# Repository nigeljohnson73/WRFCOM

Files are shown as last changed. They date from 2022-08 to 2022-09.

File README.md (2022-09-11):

# Water Rocket Flight Computer

For more background and discussion, check out [the wiki](https://github.com/nigeljohnson73/WRFCOM/wiki).

This is a small project that uses off the shelf modules as much as possible to build a data logger for attaching to a 
water bottle rocket... or any kind of vehicle. The idea is that is uses various sensors to define your position in 
3 dimensions with some additional parameters from Gyros, Accelerometers and magnetometers. All of this data being 
logged to an SD card as fast as possible and running from a small battery. The interface should be a web page from the 
on-board WiFi Access Point.

See the '[BLE Remote Controller](https://github.com/nigeljohnson73/WRFCOM-Remote)' for more on a BLE interface.

I make no apologies for the really bad coding here, and there are much better ways to do a lot of this. If you can 
help, please let me know.

Things to install
-----------------
I will assume you are comfortable with the Arduino IDE.

You should install the latest ESP boards into your board manager if you haven't already (depending on which you 
want to use). You can only install the ESP32 bitis if you are using the out-of-the-box stuff in this project.
Add these to your "Additional Boards Manager URLs" section in preferences.

```
https://arduino.esp8266.com/stable/package_esp8266com_index.json
https://raw.githubusercontent.com/espressif/arduino-esp32/gh-pages/package_esp32_dev_index.json
```

With that installed the board you want is the `Adafruit Feather ESP32-S3 No PSRAM` for the out-of-the-box project.

<!--
You will need to install the file system plugins for 
[ESP32](https://microcontrollerslab.com/install-esp32-filesystem-uploader-in-arduino-ide-spiffs/) and/or 
[ESP8266](https://randomnerdtutorials.com/install-esp8266-filesystem-uploader-arduino-ide/) depending 
on which platform youre using. This will allow you to upload the static (mostly image) files for the web pages.

I have also found the [ESP Exception Decoder](https://github.com/me-no-dev/EspExceptionDecoder) to be very useful.
-->

Code to update
--------------
To maintain the ability for you to modify settings without causing a code thing if you're working on the code, 
you should create a file called `myConfig.h` and define any of the overridable settings in `App.h` for example:

```
#define WIFI_SSID "YOUR-WIFI-SSID"
#define WIFI_PASS "YOUR-WIFI-PASS"
```

This will be discussed more in the Wiki.

Hardware required
-----------------
For the sake of sanity I used off the shelf QWIIC connecting trinket shaped sensor breakout boards. If you're good with soldering, 
you can certainly make things a lot smaller (and probably cheaper). The servo bits did need a little cutting and soldering, but 
this appeared to be well within my capability. A review of the sensors and their options will happen over in the Wiki.

The following microcontrollers have been tested and in my preferred order:

* [ESP32-S3 Feather][ESP32-S3-NOPSRAM] Dual core, BLE, WiFi 8MB flash, No PSRAM. My primary option.
* [ESP32-S3 Feather][ESP32-S3] Dual core, BLE, WiFi 4MB flash, 2MB PSRAM. The PSRAM may come in handy later.
* [ESP32-S2 Feather][ESP32-S2] Single core, No BLE, WiFi. A good board that works for all the core stuff.

### Important components
* [LIPO battery pack][LIPO-1200MAH]
* [SparkFun OpenLog][OPENLOG]
* [Simple class 10 MicroSD card][SDCARD]
* [SAM-M8Q GPS Breakout][SAM-M8Q]
* Enough [50mm QWIIC connector cables][QWIIC-CONNECTOR-50] for your sensors
* A lot of M2.3x5, 2 M2.3x10, 2 M2x5 and 4 M2.6x5 self tapping screws
* You might need some command strips to cut up and attach cables

### Optional components
* [LSM6DSOX/LIS3MDL Combo][LSM6DSOX] 9DOF IMU
* [DPS310 Barometric Pressure Sensor][DPS310]
* [PCF8523 Real Time Clock Breakout Board][PCF8523]
* [Power switch][POWER-SWITCH] and [extension cable][SWITCH-EXTENSION]

### Alternate components
* [BMP390 Barometric Pressure Sensor][BMP390]
* [LSM6DSO32 32g 6DOF Inertial Measurement Unit][LSM6DSO32]
* A smaller GPS option is the [ZOE-M8Q GPS Breakout][ZOE-M8Q] with a [u.Fl antenna][UFL-ANTENNA-LARGE]
* * There is a [small u.Fl antenna][UFL-ANTENNA-SMALL], but it can't pick up as many satelites

[SWITCH-EXTENSION]: https://thepihut.com/products/jst-ph-2-pin-cable-female-connector-150mm
[POWER-SWITCH]: https://thepihut.com/products/adafruit-switched-jst-ph-2-pin-smt-right-angle-breakout-board
[ESP32-S3]: https://thepihut.com/products/adafruit-esp32-s3-feather-with-4mb-flash-2mb-psram-stemma-qt-qwiic
[ESP32-S3-NOPSRAM]: https://thepihut.com/products/adafruit-esp32-s3-feather-with-stemma-qt-qwiic-8mb-flash-no-psram
[ESP32-S2]: https://thepihut.com/products/adafruit-esp32-s2-feather-2-mb-psram-and-stemma-qt-qwiic
[LIPO-1100MAH]: https://smile.amazon.co.uk/dp/B087LTZW61
[LIPO-1200MAH]: https://shop.pimoroni.com/products/lipo-battery-pack?variant=20429082183
[PCF8523]: https://thepihut.com/products/adafruit-pcf8523-real-time-clock-breakout-board-stemma-qt-qwiic
[BMP390]: https://shop.pimoroni.com/products/adafruit-bmp390-precision-barometric-pressure-and-altimeter-stemma-qt-qwiic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
[DPS310]: https://thepihut.com/products/adafruit-dps310-precision-barometric-pressure-altitude-sensor
[LSM6DSO32]: https://thepihut.com/products/adafruit-lsm6dso32-6-dof-accelerometer-and-gyroscope
[LSM6DSOX]: https://thepihut.com/products/adafruit-lsm6dsox-lis3mdl-precision-9-dof-imu?variant=31618642182206
[ZOE-M8Q]: https://shop.pimoroni.com/products/sparkfun-gps-breakout-zoe-m8q-qwiic?variant=31615967789139
[UFL-ANTENNA-SMALL]: https://thepihut.com/products/passive-gps-antenna-ufl-9mm-x-9mm-2dbi-gain
[UFL-ANTENNA-LARGE]: https://thepihut.com/products/passive-gps-antenna-ufl-15mm-x-15mm-1-dbi-gain
[SAM-M8Q]: https://thepihut.com/products/sparkfun-gps-breakout-chip-antenna-sam-m8q-qwiic
[OPENLOG]: https://thepihut.com/products/sparkfun-openlog
[QWIIC-CONNECTOR-100]: https://thepihut.com/products/stemma-qt-qwiic-jst-sh-4-pin-cable-100mm-long
[QWIIC-CONNECTOR-50]: https://thepihut.com/products/stemma-qt-qwiic-jst-sh-4-pin-cable
[SDCARD]: https://smile.amazon.co.uk/dp/B07R59FHVG

### Paracute option
If you want to control a parachute as well, then you will need a couple more bits:

* [9g small servo][TOWER-PRO] or a [2g micro servo][MICRO-SERVO].
* [Buck converter][BUCKY-5V]
* [Servo extension cable][SERVO-EXTENSION]

You will need to cut the extension cable and solder the female side to your microcontroller. GND, BATT for power and GPIO12 for signal. 
You will also need to splice in the buck converter into the power line (not the signal). Preferably on the controller end so you can 
use any servo.

[MICRO-SERVO]: https://www.amazon.co.uk/dp/B09NY5C4N8
[TOWER-PRO]: https://thepihut.com/products/servo-motor-sg92r-micro
[BUCKY-5V]: https://thepihut.com/products/dc-dc-automatic-step-up-down-power-module-3-15v-to-5v-600ma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
[SERVO-EXTENSION]: https://thepihut.com/products/servo-motor-sg92r-micro

### Gotta have a button?

If you want touch control for arming and starting the logging, a button is useful for testing but highly impractical for real use:

* SparkFun Qwiic Button [Green][BUTTON-GREEN] or [Red][BUTTON-RED]

[BUTTON-GREEN]: https://thepihut.com/products/sparkfun-qwiic-button-green-led
[BUTTON-RED]: https://thepihut.com/products/sparkfun-qwiic-button-red-led

Libraries required
------------------
All of these are available in the Library Manager in the Arduino IDE.

* Adafruit LC709203F (for the Feather S2/3's onboard LiPO monitor)
* SparkFun u-blox GNSS Arduino Library (for the ZOE-M8Q and SAM-M8Q GPS modules)
* SparkFun Qwiic OpenLog (for the OpenLog module)
* RTCLib (for the PCF8523 RTC module)
* Adafruit BMP3XX Library (for the BMP390 Barometric Pressure Sensor)
* Adafruit DPS310 Library (for the DSP310 Barometric Pressure Sensor)
* Adafruit LSM6DS (for the LSM6DSO32 and LSMM6DOX IMU)
* Adafruit LIS3MDL (for the LIS3MDL magnetometer)
* Adafruit Unified Sensor and Adafruit BusIO (for the LSM6DSO32/OX IMU and DPS310 Barometric Pressure Sensor)
* ESP32Servo (for the parachute trigger)
* NTPClient (for getting the network time, if enabled)
* SparkFun Qwiic Button and Qwiic Switch Library (for the Qwiic buttons)

 __NOTE:__ The ESP32Servo servo control compiles in and works on my Mac, but not on my Dell. On my Dell everything compiles and uploads fine, but the servo just does not respond. Could also be useing "PWMServo" but still unsure on Windows.

You will also need the follwing directly from GitHUB. Download them from there, unzip into your arduino library folder and remove the `-master` in the folder name.

* [ESPAsyncWebServer][ESPAsyncWebServer]
* [AsyncTCP][AsyncTCP] 

[ESPAsyncWebServer]: https://github.com/me-no-dev/ESPAsyncWebServer
[AsyncTCP]: https://github.com/me-no-dev/AsyncTCP

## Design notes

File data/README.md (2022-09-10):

These files are usually stored in on the SPIFFS section on the ESP device. They are pointless since I couldn't get SPIFFS to work.

The `user_definitiions.json` file is used by 'nRF Connect' Android app.

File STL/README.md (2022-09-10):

This folder contains the STL files used in building the payload package as outlined in this project.

## plates gps
This folder contains the options for your SAM and ZOE choices. The rest of the stack is not relevant to the choice of GPS.

## plates no-sensors
This folder contains the battery and controller stack when you are not using a sensor layer. There is an option to have a 
slightly shorter stack if you're using the SAM GPS module above the feather plate module.

## plates sensors
This folder contains the battery, sensor and controller stack when you are using a sensor layer. There is an option to have 
a slightly shorter stack if you're using the SAM GPS module above the feather plate module.

## servo all
If you are doing the parachute control section, you will need all of these pieces regardless of the size of servo you use.

## servo large
The STL files used for the larger 9g servo.

## servo tiny
The STL files used for the 2g micro-servo.

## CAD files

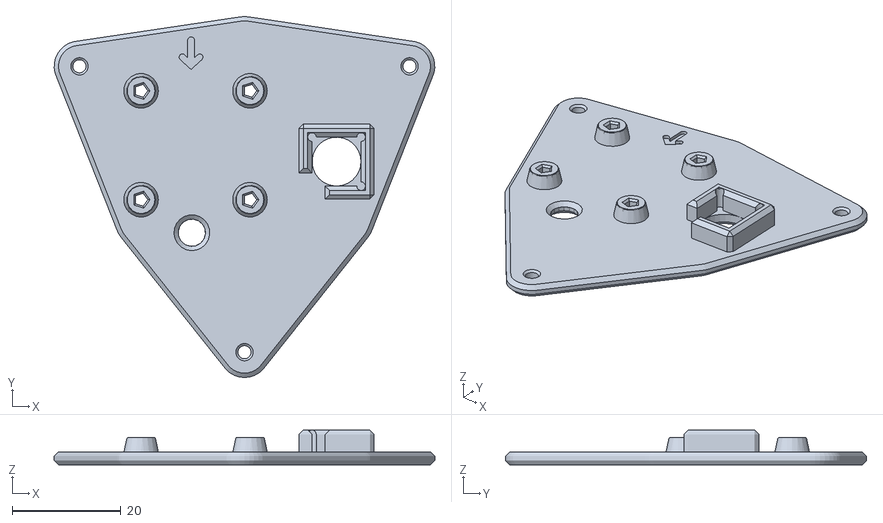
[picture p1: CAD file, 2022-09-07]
STL/plates gps/plate 04 gps zoe 09mm.stl
69.9 x 66.3 x 6.40

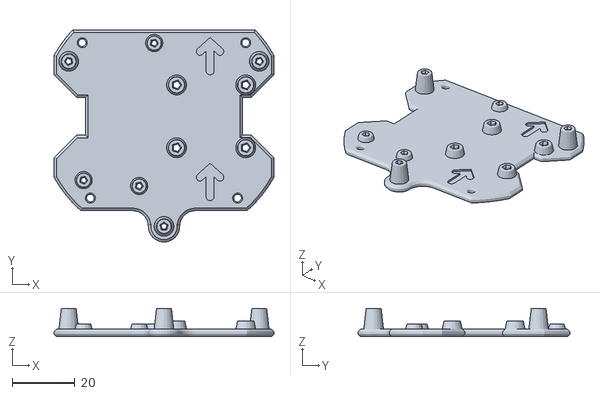
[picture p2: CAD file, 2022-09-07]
STL/plates no-sensors/plate 03 feather NOSENSORS sam.stl
70.0 x 67.5 x 8.99

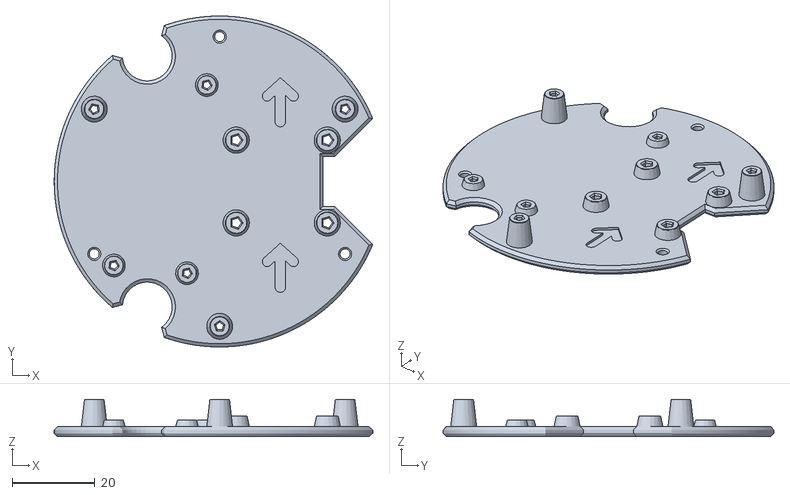
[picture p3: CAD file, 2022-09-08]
STL/plates sensors/plate 03 feather sam.stl
77.0 x 80.0 x 8.99

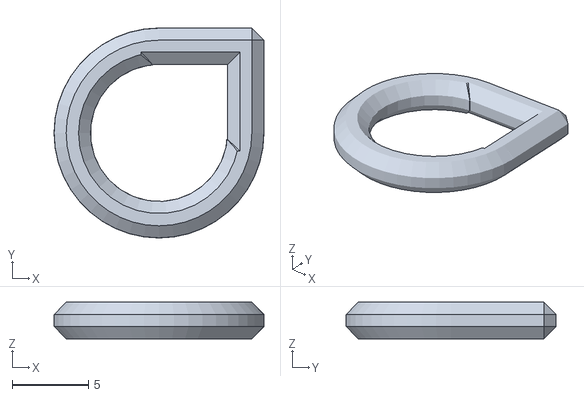
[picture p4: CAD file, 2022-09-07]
STL/servo all/servo loop.stl
13.8 x 13.8 x 2.40

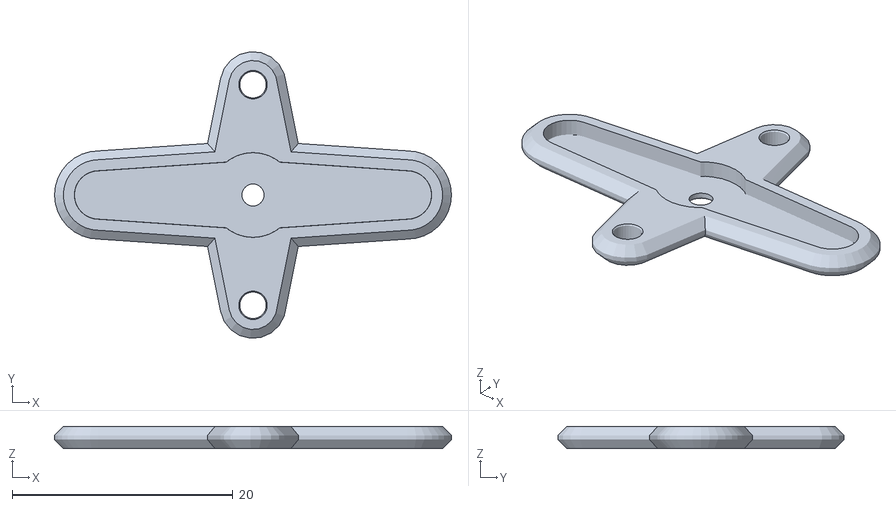
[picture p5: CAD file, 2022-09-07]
STL/servo large/servo horn.stl
36.0 x 26.0 x 2.00

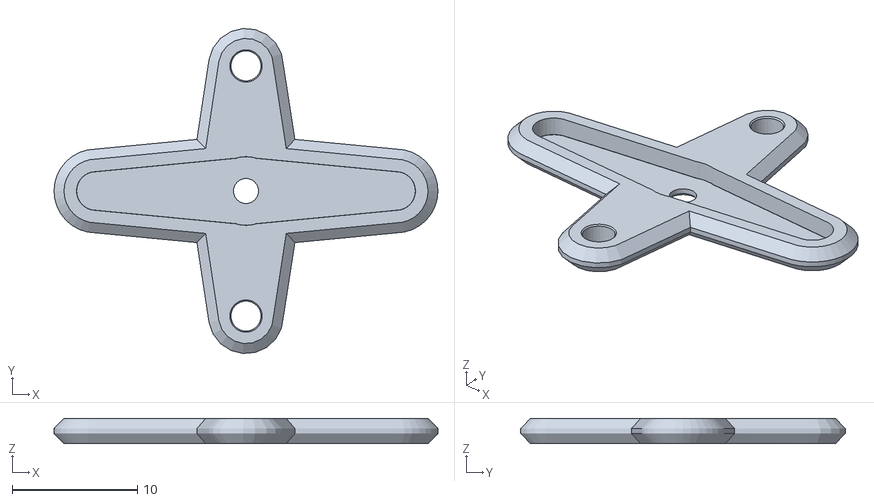
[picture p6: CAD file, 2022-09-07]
STL/servo tiny/tiny servo horn.stl
30.7 x 26.0 x 2.00

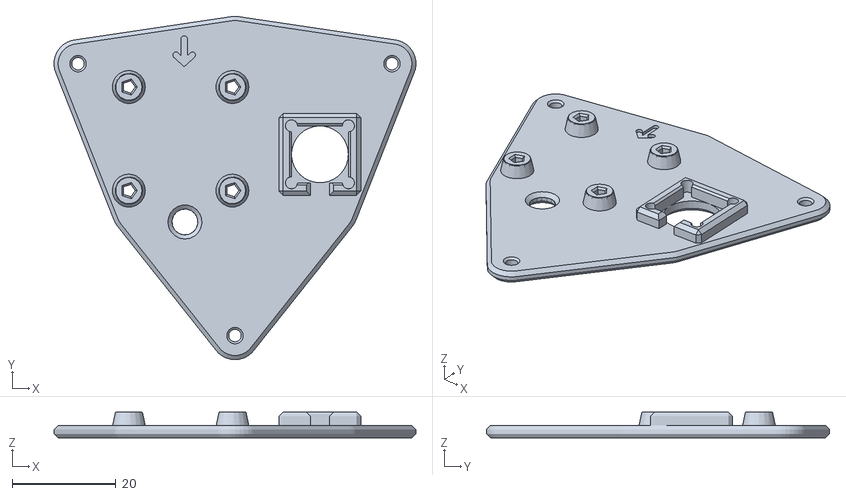
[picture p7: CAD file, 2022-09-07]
STL/plates gps/plate 04 gps zoe 15mm.stl
69.9 x 66.3 x 5.00

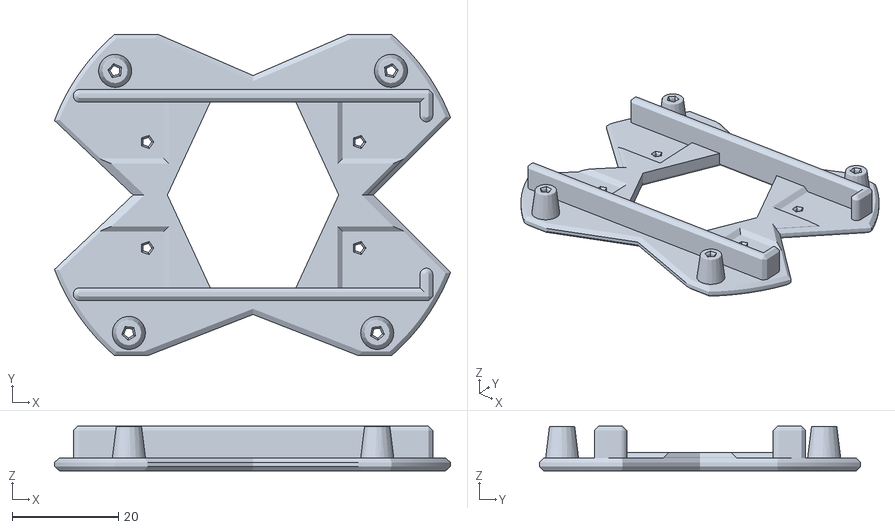
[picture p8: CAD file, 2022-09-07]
STL/plates no-sensors/plate 01 lipo 1200mAh NOSENSORS.stl
74.7 x 60.6 x 8.40

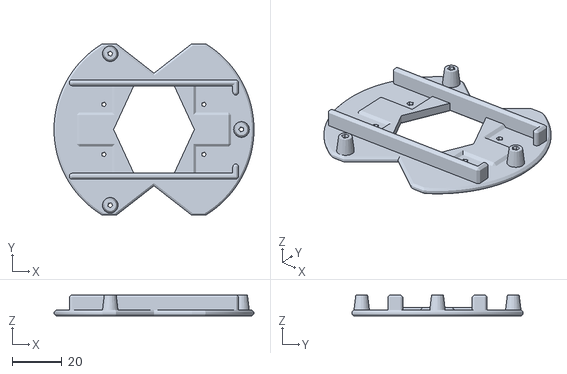
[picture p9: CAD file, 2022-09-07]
STL/plates sensors/plate 01 lipo 1200mAh.stl
80.0 x 68.6 x 8.40

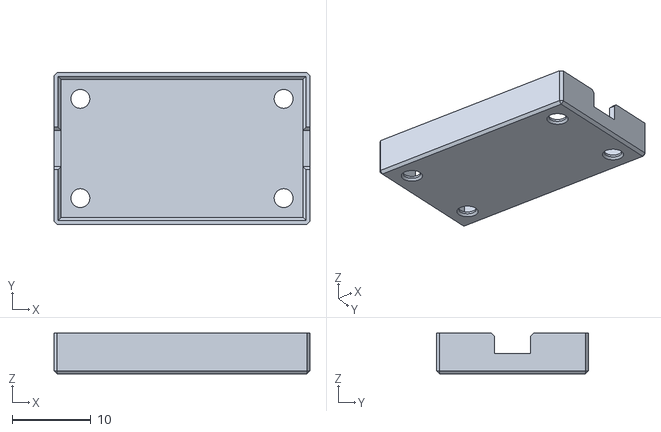
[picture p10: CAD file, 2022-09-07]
STL/servo all/servo power box lid.stl
32.5 x 19.3 x 5.20

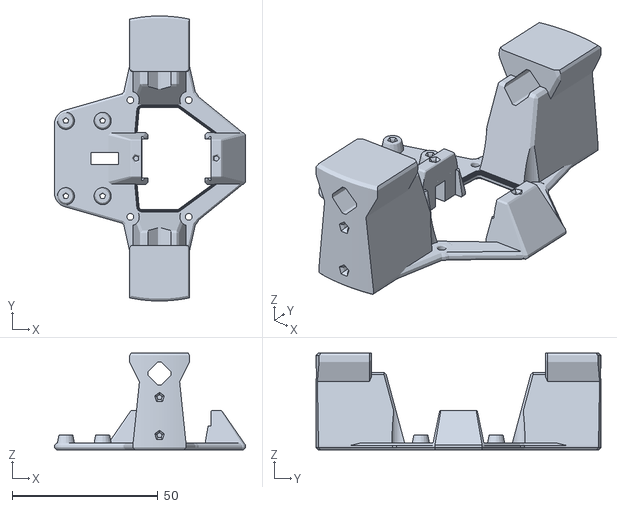
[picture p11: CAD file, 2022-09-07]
STL/servo large/servo mount.stl
65.5 x 97.7 x 33.2

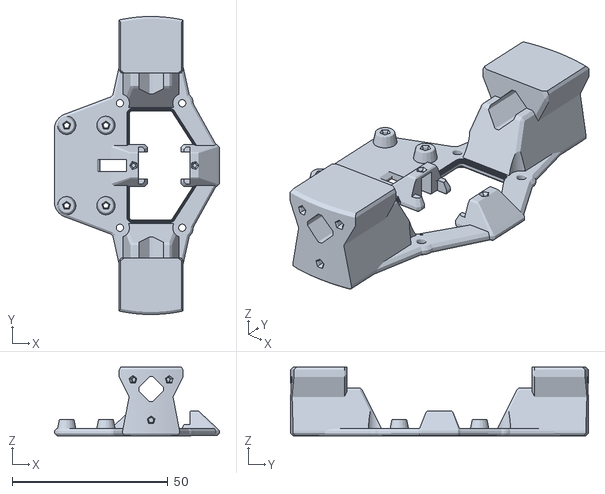
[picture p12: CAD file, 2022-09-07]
STL/servo tiny/tiny servo mount.stl
53.0 x 95.7 x 22.0

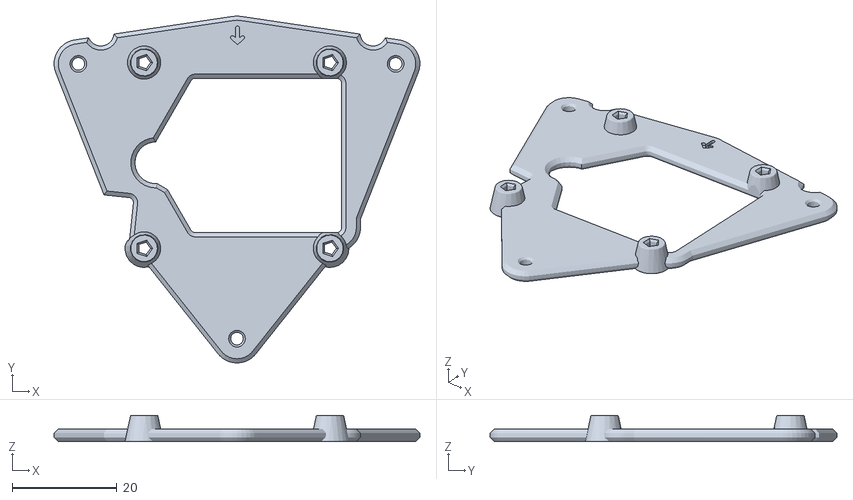
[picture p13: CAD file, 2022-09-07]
STL/plates gps/plate 04 gps sam.stl
69.9 x 66.3 x 5.00

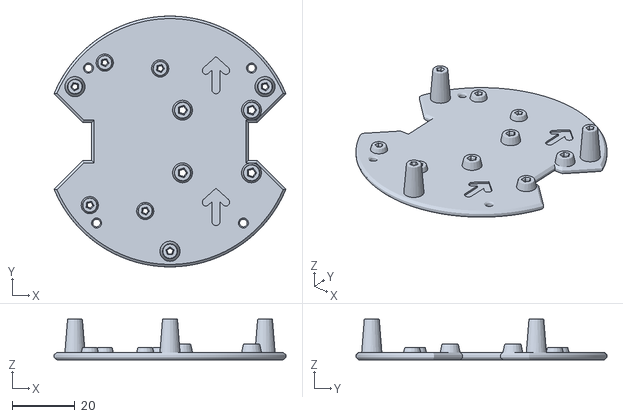
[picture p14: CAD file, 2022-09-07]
STL/plates no-sensors/plate 03 feather NOSENSORS generic.stl
74.0 x 80.0 x 13.0

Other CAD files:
STL/plates sensors/plate 03 feather.stl
STL/servo all/servo power box.stl
STL/plates sensors/plate 02 sensors x4 RTC.stl
STL/servo all/servo pin.stl
STL/servo all/servo cover.stl

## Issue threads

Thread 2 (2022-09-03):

Servo control does not work when compiled on Windows

nigeljohnson73, 2022-09-03:
On my Mac, everything compiles fine. On my Dell with the same library list. it does not. There is also a difference in compiled binary size, so there is something getting confused.

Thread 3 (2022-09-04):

Does using the max rerfresh rates on sensors help?

nigeljohnson73, 2022-09-04:
The sensor logging frequency for the project is 18Hz so all of the refresh rates on the sensors are set to the closest rate above this: what is the point of using more power if you can't get the data any faster?

For some of the sensors that use oversampling, this might be beneficial.

For things like acceleration sensors, a more extended refresh might pick up the higher peaks.

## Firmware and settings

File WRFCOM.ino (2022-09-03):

/**************
  SPIFFS doesnt work on the Feather S3 :(
  Use the "Huge App" for this in Partition Scheme, unless you really want OTA in which case use "Minimal SPIFFS"
*/

#include <Wire.h>
#include "App.h"

String espChipId() {
#ifdef ESP32
  //  int chipId = 0;
  //  for (int i = 0; i < 17; i = i + 8) {
  //
  //    chipId |= ((ESP.getEfuseMac() >> (40 - i)) & 0xff) << i;
  //  }
  uint32_t chipId = 0;
  for (int i = 0; i < 17; i = i + 8) {
    chipId |= ((ESP.getEfuseMac() >> (40 - i)) & 0xff) << i;
  }
  char buffer[20];
  sprintf(buffer, "%04X", chipId);

  return String(buffer);

#else // ESP32
  return String(ESP.getChipId());
#endif // ESP32
}

void setup() {
  Wire.begin(); // Initialise the IIC bus
  //  Wire.setClock(400000); //Go super fast
  Wire.setClock(100000); //Go less fast for GPS stability

  Serial.begin(115200);
  delay(5000);
  Serial.println();
#if _DEBUG_
  Serial.print("WRFCOM ");
  Serial.print(VERSION);
  Serial.print(": ");
  Serial.print(__DATE__);
  Serial.print(" @ ");
  Serial.print(__TIME__);
  Serial.println();
#endif

  BUT.begin(); // Switch it off early
  LED.begin();

  RTC.begin();
  EMU.begin();
  IMU.begin();
  GPS.begin();

  LOG.begin();
  SRV.begin();

  BMS.begin();
  BLE.begin();
  NOW.begin();
  NET.setHostname(DEVICE_NAME);
  NET.begin(WIFI_SSID, WIFI_PASS, WIFI_WAIT);
  WEB.begin();

#if _DEBUG_
  Serial.println ("Setup complete");
#endif
}

static unsigned long last_sweep = 0;
void loop() {
  unsigned long now = millis();

  NET.loop();
  LED.loop();
  BUT.loop();
  if (last_sweep == 0 || (now - last_sweep) >= (1000.0 / double(SENSOR_HZ))) {
    last_sweep = now;
    RTC.loop();
    BMS.loop();
    EMU.loop();
    IMU.loop();
    GPS.loop();
    SRV.loop();

    LOG.loop();
  }
  BLE.loop();
  NOW.loop();
  WEB.loop();
}

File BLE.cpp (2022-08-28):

#include "BLE.h"
#include "BLE_SVC.h"

TrBLE BLE;
TrBLE::TrBLE() {};

#if !_USE_BLE_

void TrBLE::begin() {
#if _DEBUG_ && _DISABLED_DEBUG_
  Serial.println("BLE init: disabled");
#endif
}

void TrBLE::loop() {}

#else

#include <BLEDevice.h>
#include <BLEServer.h>
#include <BLEUtils.h>
//#include <BLE2902.h>
#include <BLE2904.h>

// Used for connection monitoring
bool deviceConnected = false;
bool oldDeviceConnected = false;

// The main server
BLEServer* pServer = NULL;

// Core characteristics storage
BLECharacteristic* pWifi = NULL;
BLECharacteristic* pIpaddr = NULL;
BLECharacteristic* pBattery = NULL;
BLECharacteristic* pArmed = NULL;
BLECharacteristic* pLogging = NULL;

// Capability characteristics storage
BLECharacteristic* pCPressure = NULL;
BLECharacteristic* pCTemperature = NULL;
BLECharacteristic* pCAccelerometer = NULL;
BLECharacteristic* pCGyroscope = NULL;
BLECharacteristic* pCMagnetometer = NULL;
BLECharacteristic* pBmsEnabled = NULL;
BLECharacteristic* pGpsEnabled = NULL;
BLECharacteristic* pGpsLocked = NULL;
BLECharacteristic* pEmuEnabled = NULL;
BLECharacteristic* pImuEnabled = NULL;
BLECharacteristic* pSrvEnabled = NULL;
BLECharacteristic* pRtcEnabled = NULL;

// GPS characteristics storage
BLECharacteristic* pSiv = NULL;
BLECharacteristic* pLatitude = NULL;
BLECharacteristic* pLongitude = NULL;
BLECharacteristic* pAltitude = NULL;

// EMU characteristics storage
BLECharacteristic* pPressure = NULL;
BLECharacteristic* pTemperature = NULL;

// IMU characteristics storage
BLECharacteristic* pAccX = NULL;
BLECharacteristic* pAccY = NULL;
BLECharacteristic* pAccZ = NULL;
BLECharacteristic* pGyroX = NULL;
BLECharacteristic* pGyroY = NULL;
BLECharacteristic* pGyroZ = NULL;
BLECharacteristic* pMagX = NULL;
BLECharacteristic* pMagY = NULL;
BLECharacteristic* pMagZ = NULL;

// Core descriptors storage
BLE2904* pBle2904_wifi = NULL;
BLE2904* pBle2904_ipaddr = NULL;
BLE2904* pBle2904_battery = NULL;

// Capability descriptors storage
BLE2904* pBle2904_ctemperature = NULL;
BLE2904* pBle2904_cpressure = NULL;
BLE2904* pBle2904_caccelerometer = NULL;
BLE2904* pBle2904_cgyroscope = NULL;
BLE2904* pBle2904_cmagnetometer = NULL;
BLE2904* pBle2904_bms_enabled = NULL;
BLE2904* pBle2904_gps_enabled = NULL;
BLE2904* pBle2904_gps_locked = NULL;
BLE2904* pBle2904_emu_enabled = NULL;
BLE2904* pBle2904_imu_enabled = NULL;
BLE2904* pBle2904_srv_enabled = NULL;
BLE2904* pBle2904_rtc_enabled = NULL;

// GPS descriptors storage
BLE2904* pBle2904_siv = NULL;
BLE2904* pBle2904_latitude = NULL;
BLE2904* pBle2904_longitude = NULL;
BLE2904* pBle2904_altitude = NULL;

// EMU descriptors storage
BLE2904* pBle2904_pressure = NULL;
BLE2904* pBle2904_temperature = NULL;

// IMU descriptors storage
BLE2904* pBle2904_acc_x = NULL;
BLE2904* pBle2904_acc_y = NULL;
BLE2904* pBle2904_acc_z = NULL;
BLE2904* pBle2904_gyro_x = NULL;
BLE2904* pBle2904_gyro_y = NULL;
BLE2904* pBle2904_gyro_z = NULL;
BLE2904* pBle2904_mag_x = NULL;
BLE2904* pBle2904_mag_y = NULL;
BLE2904* pBle2904_mag_z = NULL;

// Core data values
String wifi_value = "STA";
String ipaddr_value = "192.168.999.999";
uint8_t battery_value = int(12.34);
uint8_t armed_value = true ? 1 : 0;
uint8_t logging_value = true ? 1 : 0;

// Capability data values
uint8_t ctemperature_value = true ? 1 : 0;
uint8_t cpressure_value = true ? 1 : 0;
uint8_t caccelerometer_value = false ? 1 : 0;
uint8_t cgyroscope_value = true ? 1 : 0;
uint8_t cmagnetometer_value = false ? 1 : 0;
uint8_t bms_enabled_value = true ? 1 : 0;
uint8_t gps_enabled_value = true ? 1 : 0;
uint8_t gps_locked_value = false ? 1 : 0;
uint8_t emu_enabled_value = true ? 1 : 0;
uint8_t imu_enabled_value = true ? 1 : 0;
uint8_t srv_enabled_value = true ? 1 : 0;
uint8_t rtc_enabled_value = true ? 1 : 0;

// GPS data values
uint8_t siv_value = 0;
int latitude_value = int(51.012323 * 10000000.0);
int longitude_value = (0.4612323 * 10000000.0);
int altitude_value = int(1.234 * 1000.0); //int(23.441*1000);

// EMU data values
int pressure_value = int(1013.25 * 1000.0);
int temperature_value = int(18.12 * 100.0);

// IMU data values
int accx_value = int(0.1 * 10000.);
int accy_value = int(-0.1 * 10000.);
int accz_value = int(9.79 * 10000.);
int gyrox_value = int(0.1 * 10000.);
int gyroy_value = int(-0.1 * 10000.);
int gyroz_value = int(0.0 * 10000.);
int magx_value = int(123.45 * 100.);
int magy_value = int(-123.45 * 100.);
int magz_value = int(1.234 * 100.);

// Class to handle writes to the arm control value
class MyArmCallbacks: public BLECharacteristicCallbacks {
    void onWrite(BLECharacteristic *pCharacteristic) {
      std::string value = pCharacteristic->getValue();

      if (value.length() > 0) {
        Serial.println("BLE::armCallback():");
        Serial.print(value[0] ? "TRUE" : "FALSE");
        Serial.println();
        SRV.arm(value[0] ? true : false);
      }
    }
};

// Class to handle writes to the logging control value
class MyLogCallbacks: public BLECharacteristicCallbacks {
    void onWrite(BLECharacteristic *pCharacteristic) {
      std::string value = pCharacteristic->getValue();

      if (value.length() > 0) {
        Serial.println("BLE::logCallback():");
        Serial.print(value[0] ? "TRUE" : "FALSE");
        Serial.println();
        LOG.capture(value[0] ? true : false);
      }
    }
};

// Class to hand the connection events
class MyServerCallbacks: public BLEServerCallbacks {
    void onConnect(BLEServer* pServer) {
      deviceConnected = true;
      BLEDevice::startAdvertising();
      Serial.println("Device connected");
    };

    void onDisconnect(BLEServer* pServer) {
      deviceConnected = false;
      Serial.println("Device disconnected");
    }
};
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

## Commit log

2022-07-04 Baseline shell for battery and GPS
2022-07-04 Added Servo and better initialisation
2022-07-04 added battery monitoring
2022-07-04 Documented Arduino IDE setup
2022-07-07 Compiles on ESP32 platform
2022-07-08 images converted to buttons whne SPIFFS is broke
    [WEB.cpp]
2022-07-09 Button init and loop outside of sensor scan
2022-07-10 Cludge to get Images served from the device (small ones though)
2022-07-10 Generic start up sequnece for LED button
2022-07-10 Tidied ESP32 #define management
2022-07-10 Servo now implemented
2022-07-10 Servo startup output better aligned
2022-07-10 Added Magnetomoter stubs and capability methods
2022-07-10 Handling new capabilities from IMU and GPS
2022-07-11 LED and NeoPixel handling moved to new LED class
2022-07-11 fixed typo - lipo now calculates values
    [BAT.cpp]
2022-07-11 Fixed not logging to a directory issue
    [LOG.cpp]
2022-07-11 Better handling of battery values and 64px Favicon
2022-07-11 Added new LED class to startup and loop
2022-07-13 BMS, GPS and BMP incorporated into BLE
2022-07-13 Renamed BAT to BMS
2022-07-14 DEBUG fix and comments #defines
    [WEB.cpp]
2022-07-14 BUG: Using _USE_OTA_ as false crashes device - fix this
    [App.h, NET.cpp]
2022-07-15 BLE tidy, extract definitions for REMOTE, AP->dEVICE
2022-07-16 Better battery level logic
2022-07-17 Fixed BMP typos and re-enabled RTC
    [App.h, BLE.cpp, LOG.cpp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]
2022-07-17 Disable physical button interface
2022-07-17 Stop flooding BMS
2022-07-26 Update README.md
    Added screws
2022-07-26 Update README.md
    Updated button and servo comment
2022-08-22 Allow for disabled sensors and no output
2022-08-22 Default disabled sensor output to false
2022-08-22 Documentation fo correct board manger add-ins
2022-08-22 Update README.md
    Fixed board name typo
2022-08-22 tidied up includes and ESP32 definitions
2022-08-23 Reworked data capture and calculation
    [LOG.cpp, LOG.h]
2022-08-23 Twaeked logic about chute deploy. Updated sensor rate
2022-08-23 Reduced Wire rate to reduce GPS data failures, and added placeholders for speeds
    [GPS.cpp, WRFCOM.ino]
2022-08-24 Better handling of landing detection.
2022-08-24 Buffered GPS data and smoothed over 3 frames
2022-08-25 Output units for pressure fix
    [WEB.cpp]
2022-08-27 basic logic for tracking launch and landings in place.
2022-08-28 Handling for failed refresh rate setup
    [GPS.cpp]
2022-08-28 Prepared multi IMU/EMU sensor configs
2022-08-28 renamed travel values, corrected in_flight calc
    [LOG.cpp]
2022-09-02 Added mags, and axis reversal for X/Z whn upside down in payload
    [App.h, EMU.cpp]
2022-09-02 Default to full sensors and reverse gyros
    [App.h, IMU.cpp]
2022-09-02 Correct LSM sensor specified for 9DOF sensor
    [App.h, IMU.cpp]
2022-09-03 Implemented DPS310 barometric sensor
2022-09-03 static variable clash fix
    [WRFCOM.ino]
2022-09-07 Added STL files
    [plate 01 lipo 1200mAh NOSENSORS.stl, plate 01 lipo 1200mAh.stl, plate 02 sensors x4 RTC.stl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]
2022-09-08 Added missing SAM feather plate for sensor stack
    [plate 03 feather sam.stl]
2022-09-08 Doubled sensor frequency for better resolution of smoothing
